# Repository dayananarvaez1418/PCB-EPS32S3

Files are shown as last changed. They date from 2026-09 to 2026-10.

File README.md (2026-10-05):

# PCB-ESP32S3

Placa base de desarrollo con **ESP32-S3**, pensada como punto de partida para proyectos de IoT, monitoreo ambiental y registro de datos con marca de tiempo. Incluye todo lo necesario para fabricarla y alojarla en una carcasa impresa en 3D.

## Características

- **Microcontrolador:** ESP32-S3 (Wi-Fi + Bluetooth LE)
- **Sensor de temperatura y humedad:** SHT31
- **Reloj en tiempo real:** DS3231 con respaldo de pila (portapilas B1)
- **Alimentación y programación:** USB Tipo-C
- **Pulsador de usuario:** S2
- **Dimensiones de la PCB:** ~80 × 58 mm

## Posibles aplicaciones

Este diseño no está atado a un proyecto específico. Puede servir como base para:

- Estación de monitoreo de temperatura y humedad
- Registrador de datos (data logger) con fecha y hora
- Nodo IoT que envía datos por Wi-Fi
- Plataforma de pruebas y prototipado con ESP32-S3

## Contenido del repositorio

| Carpeta | Descripción |
|---|---|
| `/esquematico` | Esquemático del circuito |
| `/pcb` | Diseño de la PCB y archivos Gerber |
| `/bom` | Lista de materiales (BOM) |
| `/enclosure` | Carcasa 3D en Fusion (`.f3d`) y archivos `.stl` para imprimir |

## Carcasa

Gabinete de dos piezas (base y tapa) diseñado en Autodesk Fusion, con abertura para el USB-C. Pensado para impresión 3D.

## Herramientas utilizadas

- [EasyEDA](https://easyeda.com/): esquemático y PCB
- Autodesk Fusion: carcasa 3D

## Estado del proyecto

Diseño completo (esquemático, PCB y carcasa). Pendiente de fabricación y pruebas de firmware.

## Cómo usarlo

1. Descarga los archivos Gerber de `/pcb` y mándalos a fabricar (por ejemplo, JLCPCB).
2. Compra los componentes según la lista de `/bom`.
3. Imprime la carcasa con los `.stl` de `/enclosure`.
4. Programa el ESP32-S3 por USB-C.

## Autora

Dayana Narváez, Universidad del Cauca

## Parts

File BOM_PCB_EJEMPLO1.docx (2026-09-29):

# Lista de materiales (BOM)

Proyecto: PCB_EJEMPLO1

Placa con ESP32-S3, sensor de temperatura/humedad SHT31, RTC DS3231 y conexión USB Tipo-C.

Total: 44 componentes en 24 líneas. Fecha: 29/09/2026.

Item | Designadores | Cant. | Descripción | Valor / N° de parte | Encapsulado | Fabricante | Proveedor / Código
1 | U1 | 1 | Módulo WiFi/Bluetooth ESP32-S3, 16MB flash, 8MB PSRAM | ESP32-S3-WROOM-1-N16R8 | WIRELM-SMD_ESP32-S3-WROOM-1 | Espressif | LCSC C2913202
2 | U2 | 1 | Sensor digital de temperatura y humedad (I2C) | SHT31A-DIS-B2.5KS | DFN-8 (2.5x2.5 mm) | Sensirion | LCSC C3664366
3 | U3 | 1 | Reloj de tiempo real RTC (I2C) | DS3231N | SO-16 (10.3x7.5 mm) | Analog Devices (Maxim) | LCSC C9900010264
4 | U4 | 1 | Convertidor USB a UART | CP2102N-A01-GQFN28 | QFN-28 (5x5 mm) | Silicon Labs | LCSC C105167
5 | U9 | 1 | Regulador LDO 3.3 V | SGM2212-3.3XKC3G/TR | SOT-223-4 | SGMICRO | LCSC C9900018517
6 | U5, U6, U8 | 3 | Diodo TVS / protección ESD 5 V | BNLESD5D5.0CT1G | SOD-523 | BORN | LCSC C20416613
7 | U7 | 1 | Diodo Schottky 1 A / 40 V | B5819W-SMA | SOD-123 | Genérico | LCSC C9900009049
8 | Q1, Q2 | 2 | Transistor NPN (circuito de auto-reset/boot) | BC818-40LT1G | SOT-23-3 | onsemi | LCSC C154797
9 | D5 | 1 | LED rojo | 19-217/R6C-AL1M2VY/3T | LED 0603 | Everlight | LCSC C72044
10 | USB1 | 1 | Conector USB Tipo-C SMD | USB4105-GF-A | TYPE-C-SMD_SBC-160S1A-20-S412 | GCT | LCSC C3020560
11 | B1 | 1 | Portapilas para batería CR1220 (respaldo del RTC) | CR1220-2 | BAT-SMD_CR1220-2 | QIJEY | LCSC C70381
12 | S2 | 1 | Pulsador táctil SMD de 4 pines (RESET / EN) | NTC013-AA1J-A160T | SW-SMD_E-SWITCH_TL1014AFXXX | Genérico | Genérico (cualquier proveedor)
13 | C1 | 1 | Condensador cerámico 1 uF, 50 V, X7R, ±10% | 1 uF / 50 V | C0603 | Genérico | Genérico (cualquier proveedor)
14 | C2 | 1 | Condensador cerámico 10 uF, 25 V, X5R, ±20% | 10 uF / 25 V | C0603 | Genérico | Genérico (cualquier proveedor)
15 | C12 | 1 | Condensador cerámico 10 uF, 10 V, X5R, ±20% | 10 uF / 10 V | C0603 | Genérico | Genérico (cualquier proveedor)
16 | C7, C9 | 2 | Condensador cerámico 2.2 uF, 50 V, X7R, ±10% | 2.2 uF / 50 V | C0603 | Genérico | Genérico (cualquier proveedor)
17 | C4, C5, C8, C10, C11, C30 | 6 | Condensador cerámico 100 nF, 50 V, X7R, ±10% | 100 nF / 50 V | C0603 | Genérico | Genérico (cualquier proveedor)
18 | R1, R5, R6 | 3 | Resistencia 0 ohm (puente), ±1% | 0 ohm | R0603 | Genérico | Genérico (cualquier proveedor)
19 | R3, R4, R12, R16, R20, R21, R22, R25, R27 | 9 | Resistencia 10 kohm, ±1%, 1/10 W | 10 kohm | R0603 | Genérico | Genérico (cualquier proveedor)
20 | R9, R10 | 2 | Resistencia 5.1 kohm, ±1% (CC del USB-C) | 5.1 kohm | R0603 | Genérico | Genérico (cualquier proveedor)
21 | R11 | 1 | Resistencia 1 kohm, ±1% (LED) | 1 kohm | R0603 | Genérico | Genérico (cualquier proveedor)
22 | R13 | 1 | Resistencia 22.1 kohm, ±1% | 22.1 kohm | R0603 | Genérico | Genérico (cualquier proveedor)
23 | R14 | 1 | Resistencia 47.5 kohm, ±1% | 47.5 kohm | R0603 | Genérico | Genérico (cualquier proveedor)
24 | R15 | 1 | Resistencia 2 kohm, ±1% | 2 kohm | R0603 | Genérico | Genérico (cualquier proveedor)

Notas

Los componentes marcados como "Genérico" (resistencias, condensadores y pulsador) se consiguen en cualquier proveedor; basta con respetar valor, voltaje, tolerancia y encapsulado indicados.

Las piezas con código LCSC se pueden pedir directamente en LCSC / JLCPCB.

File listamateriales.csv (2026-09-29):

Item | Designadores | Cantidad | Descripción | Valor / Parte | Encapsulado | Fabricante | N° parte fabricante | LCSC
1 | U1 | 1 | Módulo WiFi/BLE ESP32-S3, 16MB flash, 8MB PSRAM | ESP32-S3-WROOM-1-N16R8 | WIRELM-SMD_ESP32-S3-WROOM-1 | Espressif | ESP32-S3-WROOM-1-N16R8 | C2913202
2 | U2 | 1 | Sensor de temperatura y humedad I2C | SHT31A-DIS-B2.5KS | DFN-8_L2.5-W2.5-P0.50 | Sensirion | SHT31A-DIS-B2.5KS | C3664366
3 | U3 | 1 | RTC (reloj de tiempo real) I2C | DS3231N | SO-16 (10.3x7.5mm) | Analog Devices / Maxim | DS3231N | C9900010264
4 | U4 | 1 | Convertidor USB a UART | CP2102N-A01-GQFN28 | QFN-28 (5x5mm) | Silicon Labs | CP2102N-A01-GQFN28R | C105167
5 | U9 | 1 | Regulador LDO 3.3V | SGM2212-3.3XKC3G/TR | SOT-223-4 | SGMICRO | SGM2212-3.3XKC3G/TR | C9900018517
6 | U5, U6, U8 | 3 | Diodo TVS/ESD de protección | BNLESD5D5.0CT1G | SOD-523 | BORN | BNLESD5D5.0CT1G | C20416613
7 | U7 | 1 | Diodo Schottky 1A / 40V | B5819W-SMA | SOD-123 | - | B5819W-SMA | C9900009049
8 | Q1, Q2 | 2 | Transistor NPN (auto-reset/boot) | BC818-40LT1G | SOT-23-3 | onsemi | BC818-40LT1G | C154797
9 | D5 | 1 | LED rojo | 19-217/R6C-AL1M2VY/3T | LED0603 | Everlight | 19-217/R6C-AL1M2VY/3T | C72044
10 | USB1 | 1 | Conector USB Tipo-C SMD | USB4105-GF-A | TYPE-C-SMD_SBC-160S1A-20-S412 | GCT | USB4105-GF-A | C3020560
11 | B1 | 1 | Portapilas CR1220 (batería RTC) | CR1220-2 | BAT-SMD_CR1220-2 | QIJEY | CR1220-2 | C70381
12 | S2 | 1 | Pulsador SMD (BOOT/RESET) | TL1014AFXXX | SW-SMD_E-SWITCH_TL1014AFXXX | E-Switch | TL1014AF | Pendiente
13 | C1 | 1 | Condensador cerámico 1uF 50V | 1uF | C0603 | - | - | Pendiente
14 | C2, C12 | 2 | Condensador cerámico 10uF (25V / 10V) | 10uF | C0603 | - | - | Pendiente
15 | C7, C9 | 2 | Condensador cerámico 2.2uF 50V | 2.2uF | C0603 | - | - | Pendiente
16 | C4, C5, C8, C10, C11, C30 | 6 | Condensador cerámico 100nF (0.1uF) | 100nF | C0603 | - | - | Pendiente
17 | R1, R5, R6 | 3 | Resistencia 0 ohm | 0R | R0603 | - | - | Pendiente
18 | R3, R4, R12, R16, R20, R21, R22, R25, R27 | 9 | Resistencia 10k ohm | 10k | R0603 | - | - | Pendiente
19 | R9, R10 | 2 | Resistencia 5.1k ohm (CC del USB-C) | 5.1k | R0603 | - | - | Pendiente
20 | R11 | 1 | Resistencia 1k ohm (LED) | 1k | R0603 | - | - | Pendiente
21 | R13 | 1 | Resistencia 22.1k ohm 1% | 22.1k | R0603 | - | - | Pendiente
22 | R14 | 1 | Resistencia 47.5k ohm 1% | 47.5k | R0603 | - | - | Pendiente
23 | R15 | 1 | Resistencia 2k ohm | 2k | R0603 | - | - | Pendiente

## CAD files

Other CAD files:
CARCAZAPCB.f3d

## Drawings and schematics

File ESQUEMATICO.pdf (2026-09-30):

## Reloj de tiempo real

## REGULADOR DE VOLTAJE SACA 3V3

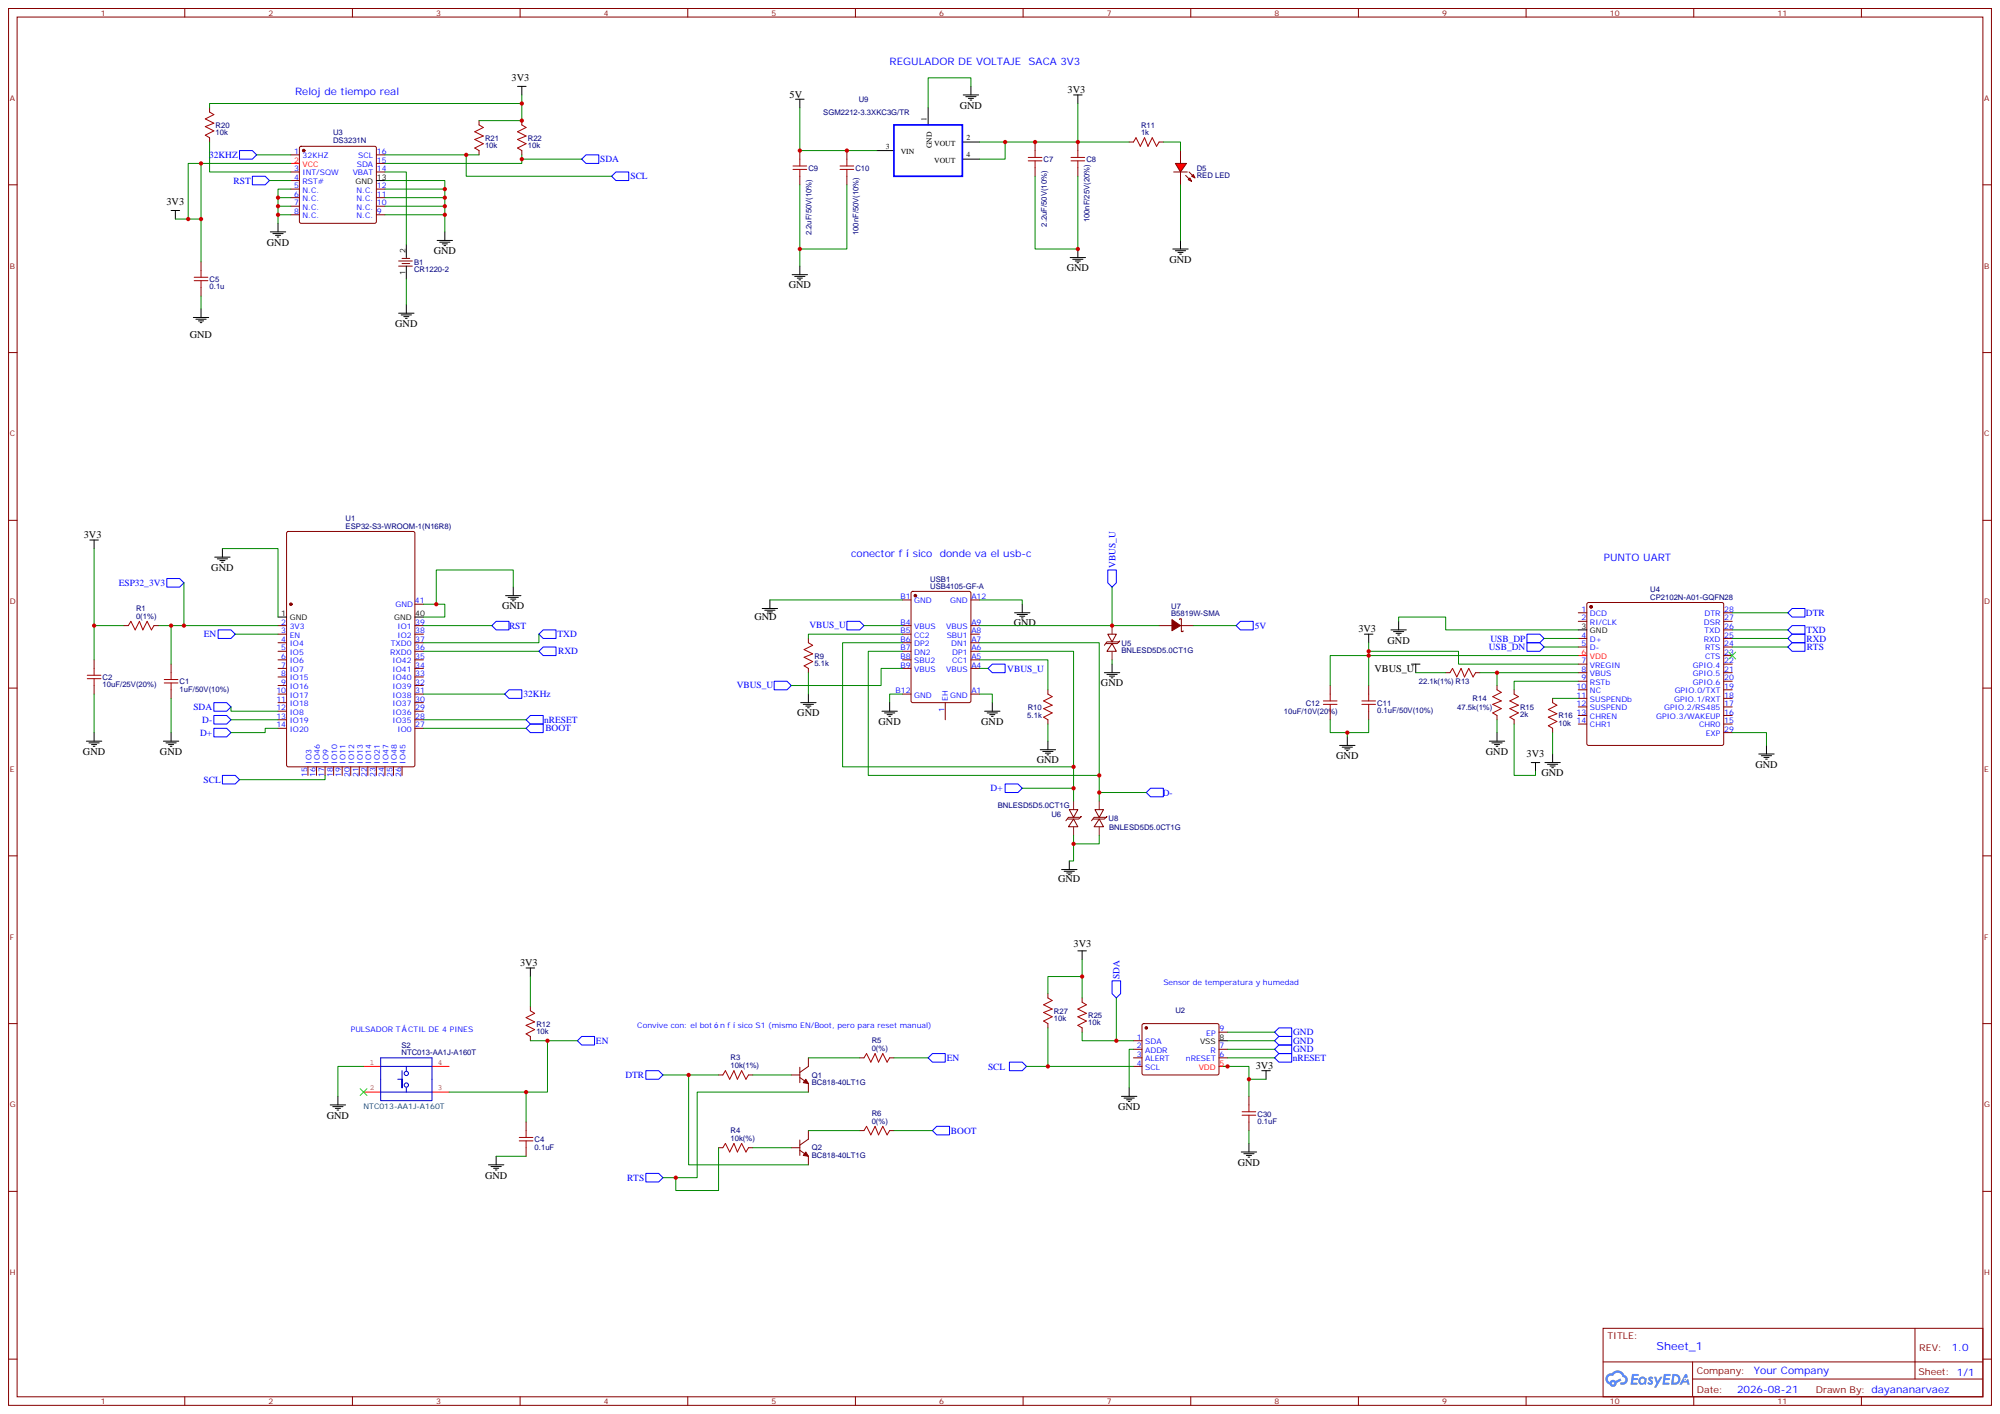
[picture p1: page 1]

conector f sico donde va el usb-c

Sensor de temperatura y humedad

Convive con: el bot n f sico S1 (mismo EN/Boot, pero para reset manual)

PULSADOR T CTIL DE 4 PINES

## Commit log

2026-09-30 Add files via upload
    Esquemático de una placa basada en el módulo ESP32-S3-WROOM-1 (N16R8). Incluye alimentación por USB Tipo-C con regulador de 3.3 V, programación mediante convertidor USB-UART CP2102N con circuito de auto-reset, sensor de temperatura y humedad SHT31 y reloj de tiempo real DS3231 (ambos por I2C) con batería de respaldo CR1220.
2026-10-05 Add files via upload
    Carcasa 3D para PCB con ESP32
    Enclosure diseñado en Autodesk Fusion para alojar una PCB basada en ESP32, con conector USB-C, portapilas B1 y pulsador S2. La placa fue diseñada en EasyEDA y su modelo 3D se importó a Fusion como re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
    [CARCAZAPCB.f3d]
